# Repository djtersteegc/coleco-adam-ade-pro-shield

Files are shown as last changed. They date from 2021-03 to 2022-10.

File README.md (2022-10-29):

# coleco-adam-ade-pro-shield
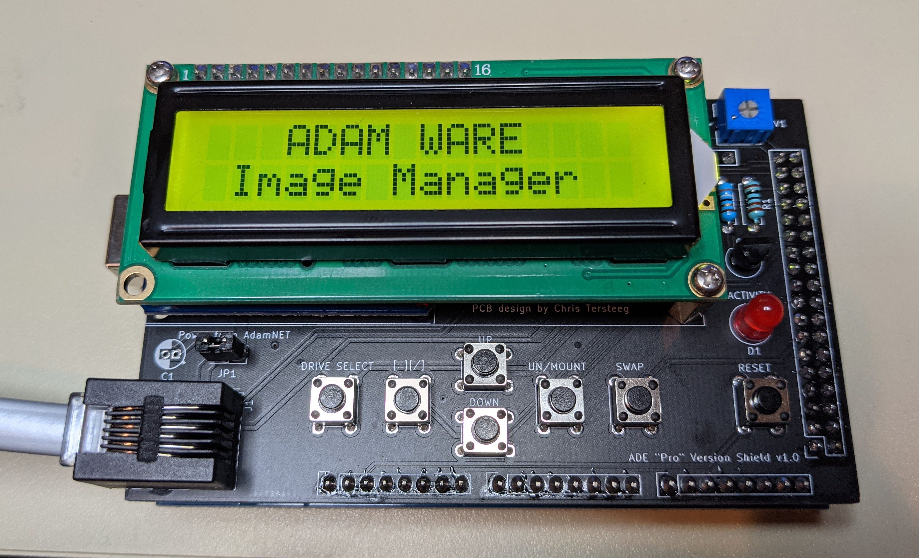
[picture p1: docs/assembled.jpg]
assembled


This custom Arduino Mega 2560 shield compatible with [AdamNet Drive Emulator](https://github.com/Kalidomra/AdamNet-Drive-Emulator) (ADE) software by Sean Myers. The design is built to be compatible with the "Pro" version of the software available precompiled and ready for flashing on his repo.  I was inspired by John Lundy's original ADE shield design, but wanted something with a slightly smaller footprint and different SD card module.  This was accomplished by putting the LCD on stand-offs and mounting the card (and some other components) underneath it.

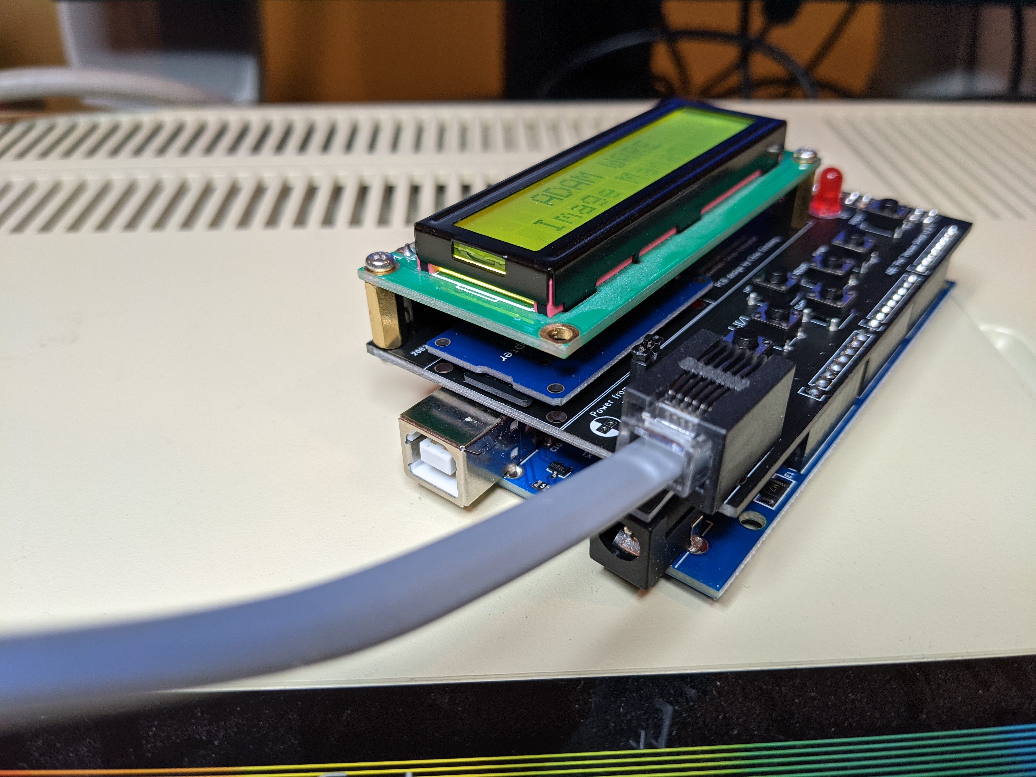
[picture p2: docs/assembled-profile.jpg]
assembled-profile


All components can be sourced from the usual low cost China based vendors for a total build cost of around $20.  Please see the assembly page for more details.

[Hardware Component Choices and Assembly](https://djtersteegc.github.io/coleco-adam-ade-pro-shield/assembly.html)

An interactive BOM and parts placement diagram is also available.

[Interactive Bill of Materials (BOM)](https://djtersteegc.github.io/coleco-adam-ade-pro-shield/ibom.html)

STL's and the [DesignSpark Mechanical](https://www.rs-online.com/designspark/mechanical-software) source file for a 3D printable enclosure are in the **enclosure** directory. There is a difference in power and USB connectors locations between the offical 2560 boards and the Chinese copies you can buy with the CH340 serial chips.  Pick the body file that matches the type you are using. The lid is snap fit, but you can also add a single M3x10mm screw if you wish to secure it further. Make sure to print seven copies of the button file.

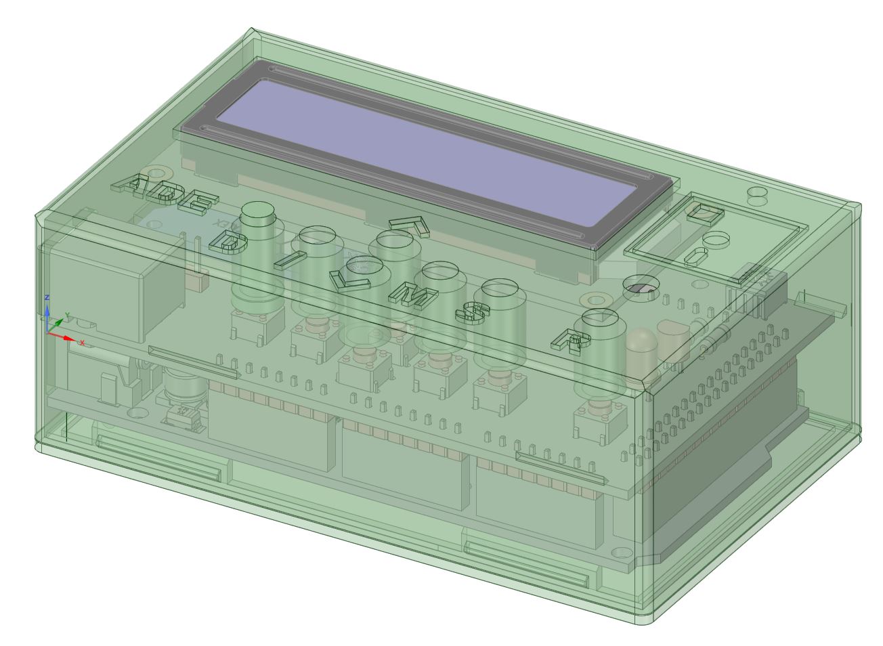
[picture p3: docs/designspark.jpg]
designspark


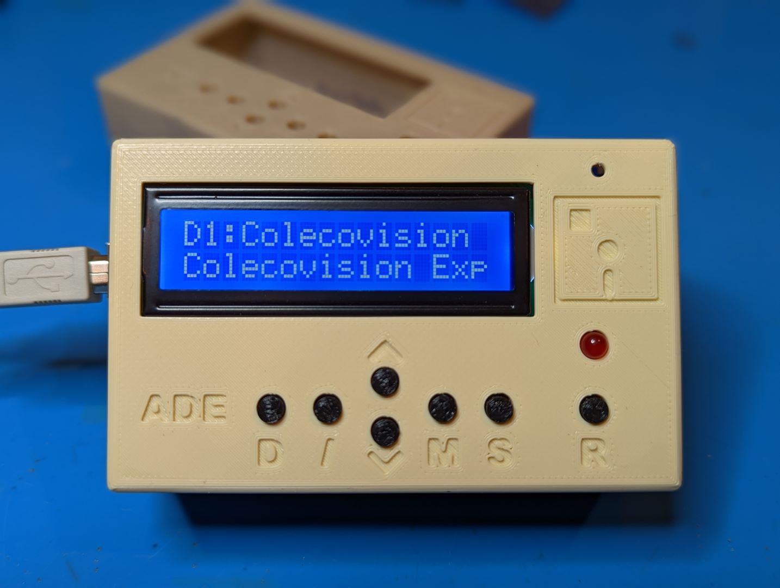
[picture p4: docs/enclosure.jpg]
enclosure


If you wish to power your board from the 5V ADAMnet line, simply install and close jumper JP1.  Be warned there is no protection on the board from back feeding voltage into the Adam if you also power the Arduino via USB or it's DC jack connector, so only close this jumper when not using another power source on the Arduino.

# Getting a Board

If I have extra PCB's, they will be listed on Tindie (soon...).

Otherwise you can download the Gerbers and use your favorite fab (JLCPCB, PCBWay, etc.) to make your own batch.  It's a standard two layer, 1oz copper board with dimensions of 99mm x 61mm so it squeaks under the 100mm x 100mm limit of the cheap Chinese fabs.

# Hardware Revisions

### Version 1.0

Tested and working.

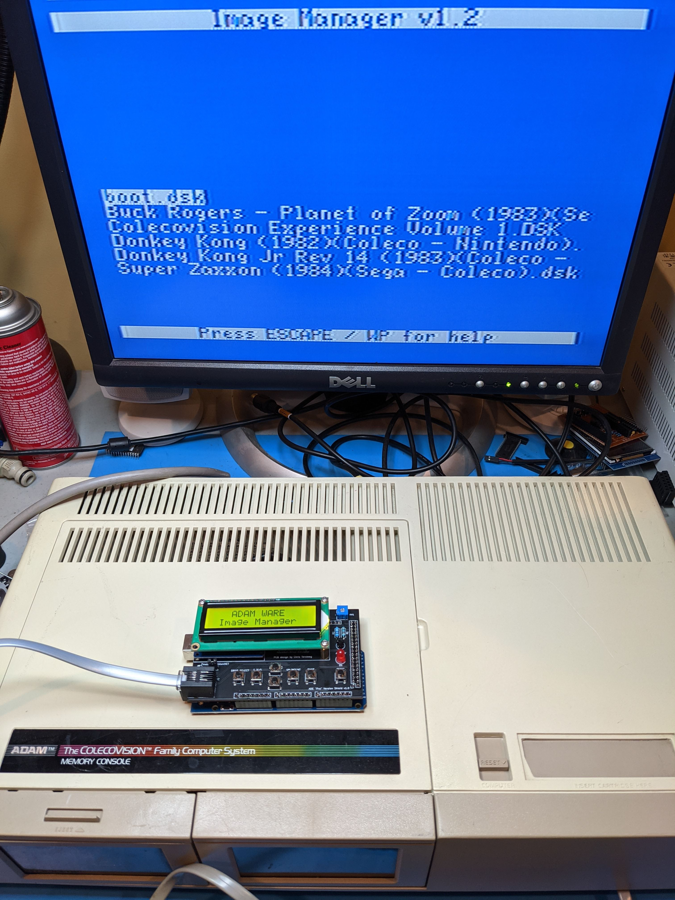
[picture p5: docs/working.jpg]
working


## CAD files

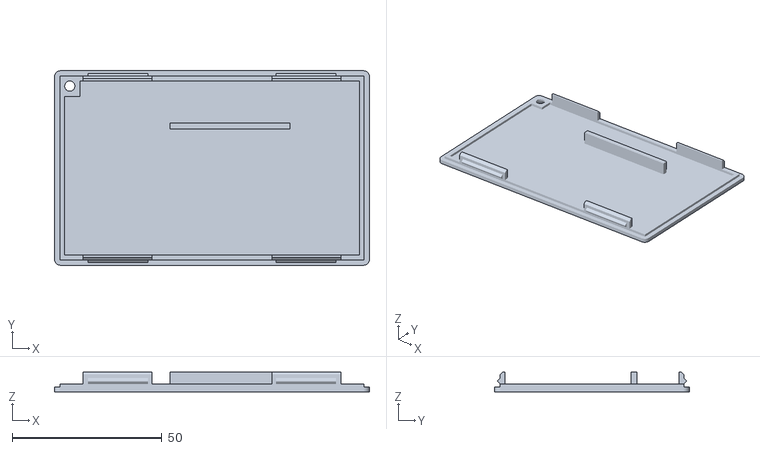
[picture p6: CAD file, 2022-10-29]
enclosure/ade lid.stl
105.2 x 65.0 x 6.60

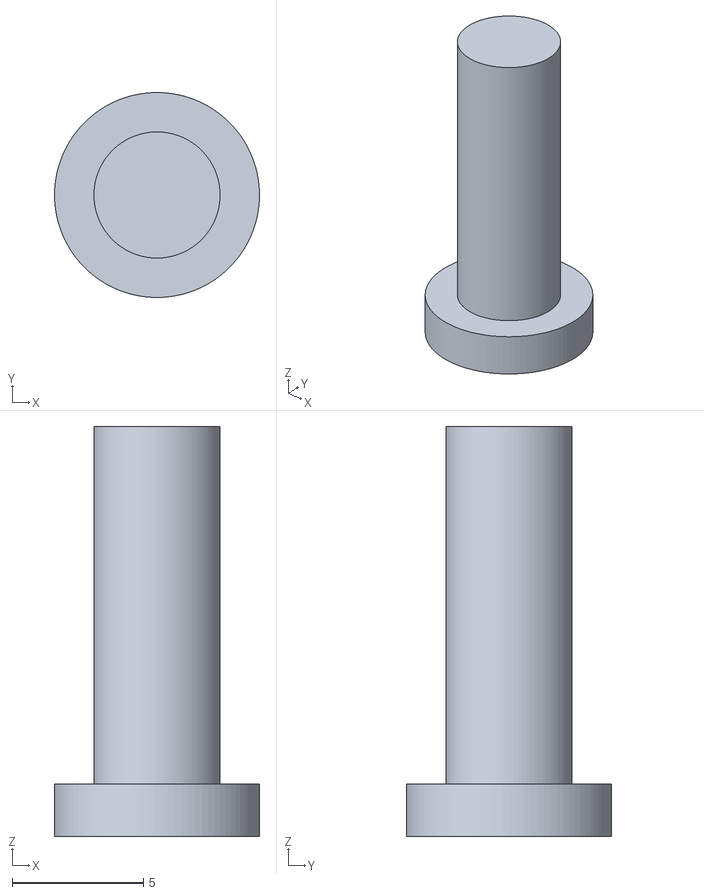
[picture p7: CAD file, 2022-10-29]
enclosure/ade button.stl
7.80 x 7.80 x 15.6

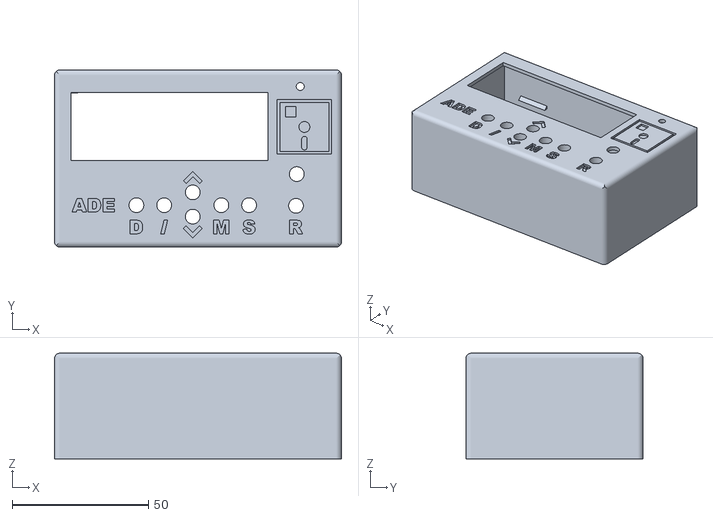
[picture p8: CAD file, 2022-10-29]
enclosure/ade body.stl
105.2 x 65.0 x 38.7

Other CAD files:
enclosure/ade body - ch340 clone.stl

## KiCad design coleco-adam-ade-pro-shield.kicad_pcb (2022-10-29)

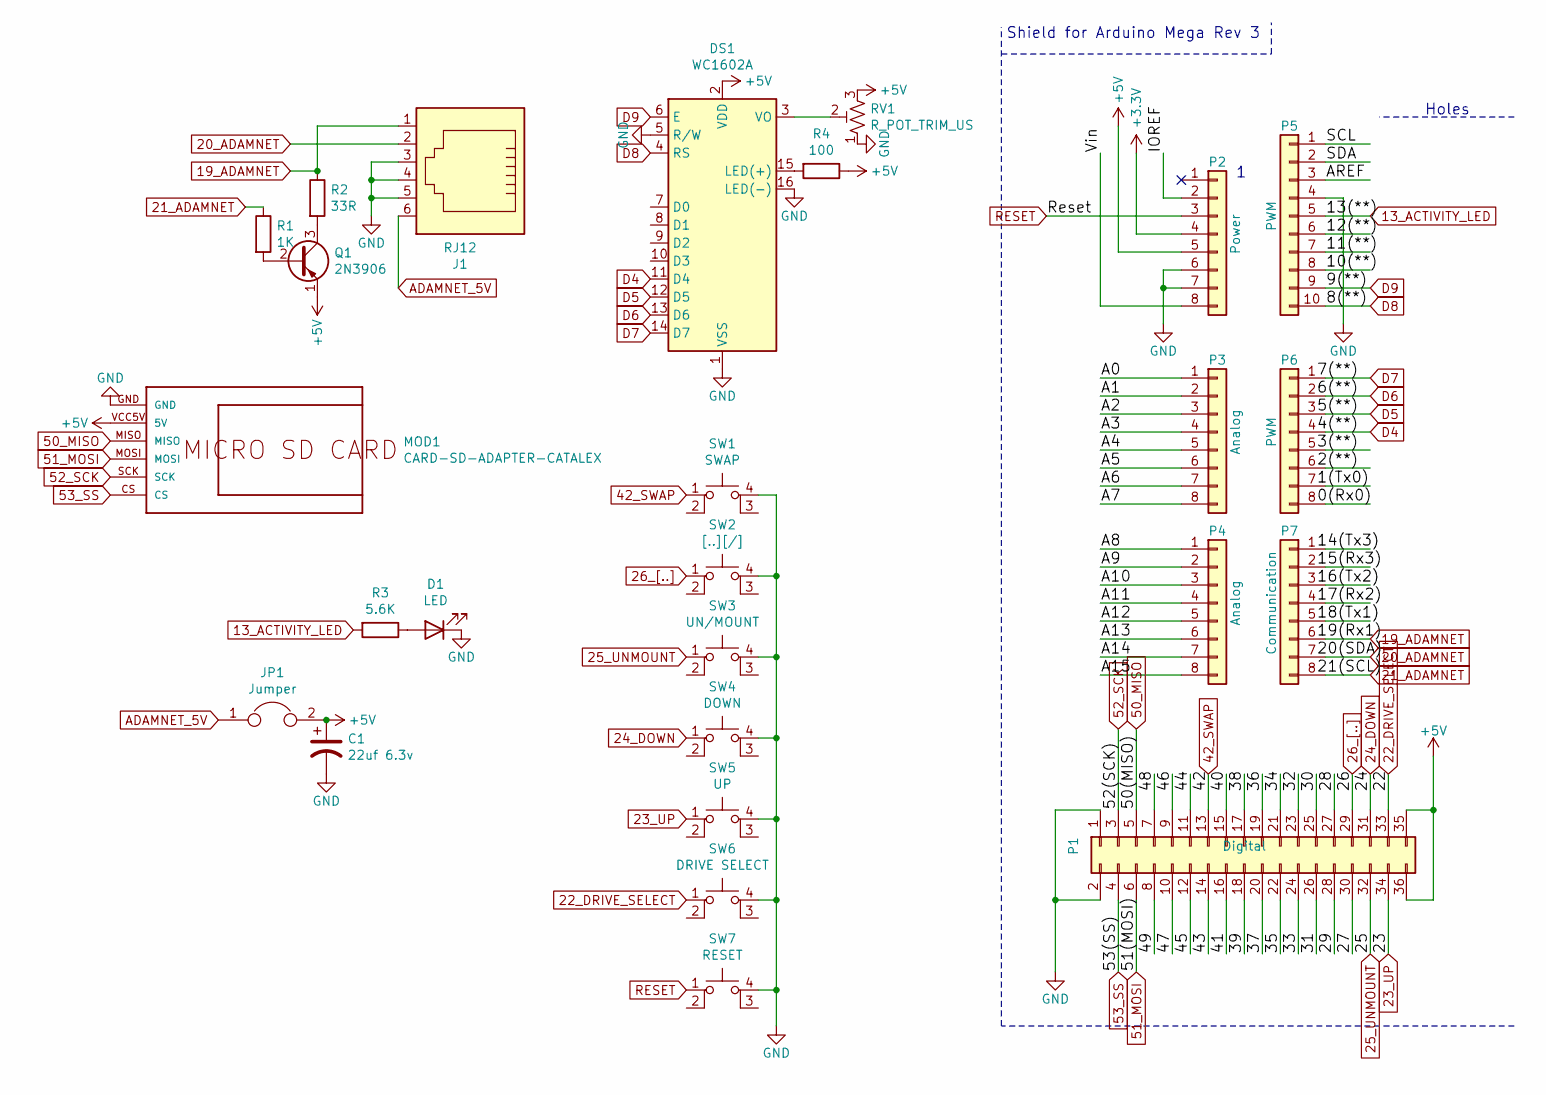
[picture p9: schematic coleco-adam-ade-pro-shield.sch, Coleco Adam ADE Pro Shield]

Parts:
C1: 22uf 6.3v; CP_Radial_D4.0mm_P1.50mm
D1: LED; LED_D5.0mm
DS1: WC1602A
J1: RJ12; RJ12_Amphenol_54601
JP1: Jumper; PinHeader_2x01_P2.54mm_Vertical
MOD1: CARD-SD-ADAPTER-CATALEX; Catalex-MicroSD-Card-Down
P1: Digital; Socket_Strip_Arduino_2x18
P2: Power; Socket_Strip_Arduino_1x08
P3, P4: Analog; Socket_Strip_Arduino_1x08
P5: PWM; Socket_Strip_Arduino_1x10
P6: PWM; Socket_Strip_Arduino_1x08
P7: Communication; Socket_Strip_Arduino_1x08
Q1: 2N3906; TO-92_Inline
R1: 1K; R_Axial_DIN0207_L6.3mm_D2.5mm_P7.62mm_Horizontal
R2: 33R; R_Axial_DIN0207_L6.3mm_D2.5mm_P7.62mm_Horizontal
R3: 5.6K; R_Axial_DIN0207_L6.3mm_D2.5mm_P7.62mm_Horizontal
R4: 100; R_Axial_DIN0207_L6.3mm_D2.5mm_P7.62mm_Horizontal
RV1: R_POT_TRIM_US; TRIM_3362P-1-103
SW1: SWAP; SW_TH_Tactile_Omron_B3F-10xx
SW2: [..][/]; SW_TH_Tactile_Omron_B3F-10xx
SW3: UN/MOUNT; SW_TH_Tactile_Omron_B3F-10xx
SW4: DOWN; SW_TH_Tactile_Omron_B3F-10xx
SW5: UP; SW_TH_Tactile_Omron_B3F-10xx
SW6: DRIVE SELECT; SW_TH_Tactile_Omron_B3F-10xx
SW7: RESET; SW_TH_Tactile_Omron_B3F-10xx

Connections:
13_ACTIVITY_LED: P5.5, R3.2
19_ADAMNET: J1.1, P7.6, R2.1
20_ADAMNET: J1.2, P7.7
21_ADAMNET: P7.8, R1.1
22_DRIVE_SELECT: P1.33, SW6.1
23_UP: P1.34, SW5.1
24_DOWN: P1.31, SW4.1
25_UNMOUNT: P1.32, SW3.1
26_[..]: P1.29, SW2.1
42_SWAP: P1.13, SW1.1
50_MISO: MOD1.MISO, P1.5
51_MOSI: MOD1.MOSI, P1.6
52_SCK: MOD1.SCK, P1.3
53_SS: MOD1.CS, P1.4
+3V3: P2.4
+5V: C1.1, DS1.2 (VDD), JP1.2, MOD1.VCC5V (5V), P1.35, P1.36, P2.5, Q1.1 (E), R4.1, RV1.3
/10(**): P5.8
/11(**): P5.7
/12(**): P5.6
/27: P1.30
/28: P1.27
/29: P1.28
/30: P1.25
/31: P1.26
/32: P1.23
/33: P1.24
/34: P1.21
/35: P1.22
/36: P1.19
/37: P1.20
/38: P1.17
/39: P1.18
/40: P1.15
/41: P1.16
/43: P1.14
/44: P1.11
/45: P1.12
/46: P1.9
/47: P1.10
/48: P1.7
/49: P1.8
/A0: P3.1
/A1: P3.2
/A2: P3.3
/A3: P3.4
/A4: P3.5
/A5: P3.6
/A6: P3.7
/A7: P3.8
/A8: P4.1
/A9: P4.2
/A10: P4.3
/A11: P4.4
/A12: P4.5
/A13: P4.6
/A14: P4.7
/A15: P4.8
/AREF: P5.3
/IOREF: P2.2
/SCL: P5.1
/SDA: P5.2
/Vin: P2.8
ADAMNET_5V: J1.6, JP1.1
D4: DS1.11 (D4), P6.4
D5: DS1.12 (D5), P6.3
D6: DS1.13 (D6), P6.2
D7: DS1.14 (D7), P6.1
D8: DS1.4 (RS), P5.10
D9: DS1.6 (E), P5.9
GND: C1.2, D1.1 (K), DS1.1 (VSS), DS1.5 (R/W), DS1.16 (LED(-)), J1.3, J1.4, J1.5, MOD1.GND, P1.1, P1.2, P2.6, P2.7, P5.4, RV1.1, SW1.4 (A), SW2.4 (A), SW3.4 (A), SW4.4 (A), SW5.4 (A), SW6.4 (A), SW7.4 (A)
unnamed: D1.2 (A), R3.1
unnamed: DS1.3 (VO), RV1.2
unnamed: DS1.15 (LED(+)), R4.2
unnamed: Q1.2 (B), R1.2
unnamed: Q1.3 (C), R2.2
RESET: P2.3, SW7.1

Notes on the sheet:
Shield for Arduino Mega Rev 3
Holes

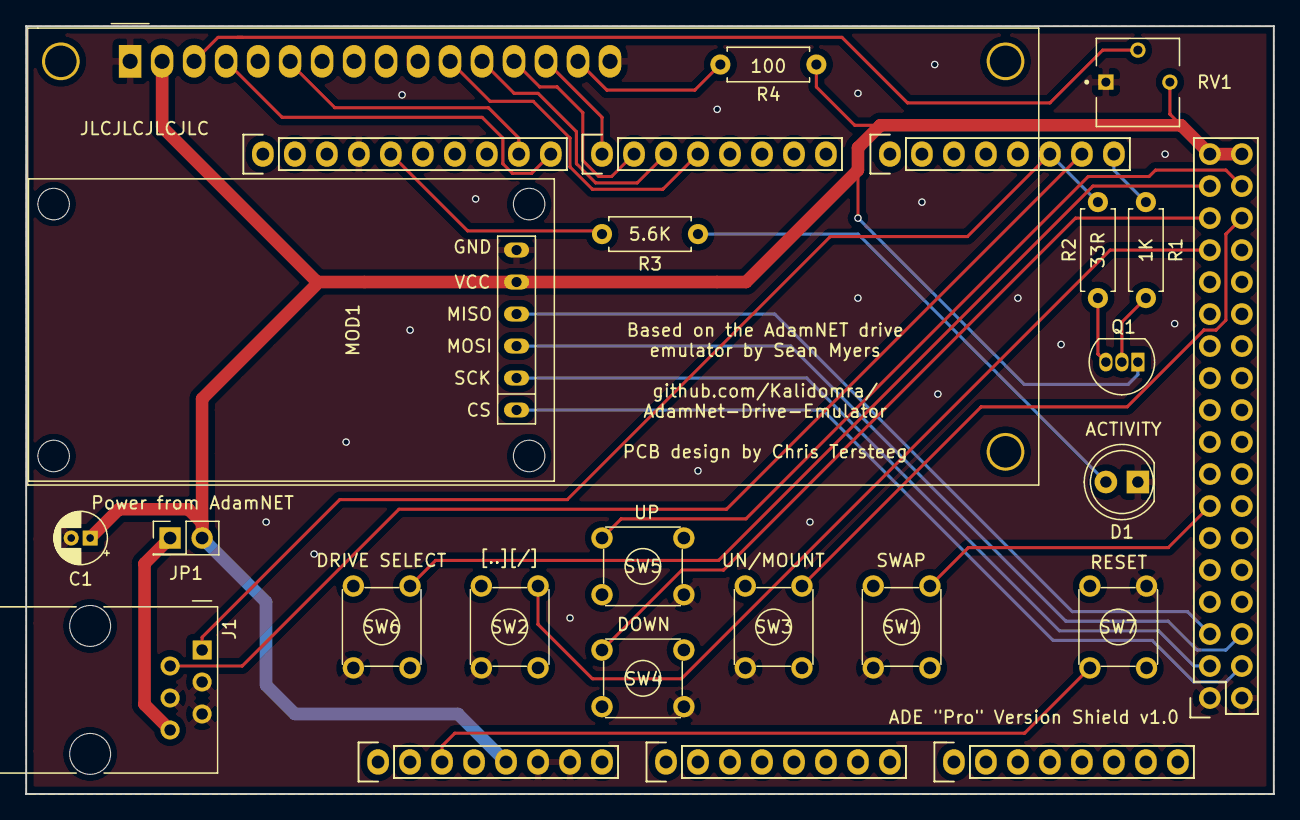
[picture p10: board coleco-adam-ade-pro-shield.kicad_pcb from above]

Board: 2 copper layers, 99.1 x 61.0 mm, 26 parts (0 on the bottom side), 29 nets.

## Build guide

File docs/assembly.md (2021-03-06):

# Hardware Component Choices and Assembly

[Interactive Bill of Materials (BOM)](ibom.html)

### LCD and Mounting

Any old HD44780 1602 LCD from Aliexpress/eBay for ~$2.  You do not need the I2C module, LCD is connected in 4bit parallel mode. For the stand-off mounts you need [11mm M2.5 spacers](https://www.aliexpress.com/item/1005001478740318.html) and screws (same as used mount a Raspberry Pi hat)

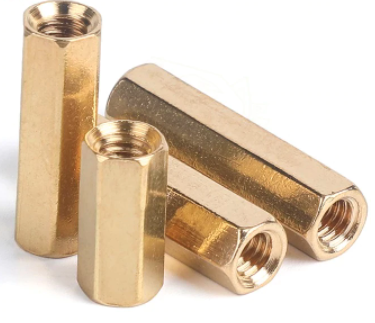
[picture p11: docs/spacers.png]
spacers
 

and a 16 pin (16p) female header.  I buy the  [40 pin packs](https://www.aliexpress.com/item/32724478308.html) and cut them down.

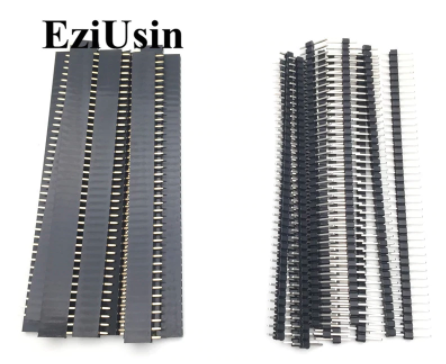
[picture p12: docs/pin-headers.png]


### Micro SD Card Connector

This is the common push-push [Micro SD module](https://www.aliexpress.com/item/1873549637.html) with level shifters.  Sometimes it may say "Catalex" (maybe the original designer?) on the back of the PCB.  You will need to remove the pre-soldered right angle header they all seem to come with so you can mount it upside down on the ADE shield board.

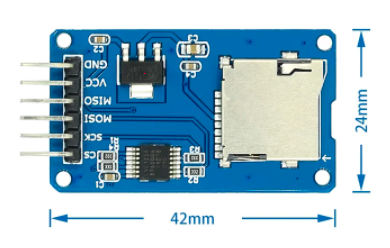
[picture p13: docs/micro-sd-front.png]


### RJ12 Connector

The "longer" type RJ12 connector from [Aliexpress](https://www.aliexpress.com/item/32865986654.html) work fine if you don't want to spring for the official [Amphenol](https://www.digikey.com/en/products/detail/amphenol-icc-fci/54601-906WPLF/4242891) version.  Remember, ADAMnet takes a RJ12 reverse cable, I get mine at [Monoprice](https://www.monoprice.com/product?p_id=939)

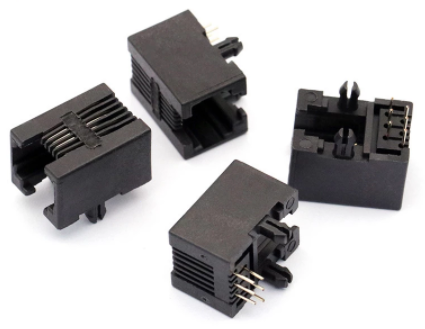
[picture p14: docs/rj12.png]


### Bulk Capacitors

C1 is a bulk storage capacitor for the 5V rail.  It is optional since the Arduino already has caps on-board, but if you have a marginal ADAMnet 5V line or experience other power issues, they could help stabilize the overall board.  Any value between 10uf to 47uf is fine.

### Resistors

Either 1/4W or 1/8W can be used in all locations.

R3 controls the activity LED brightness. The value listed is based on John Lundy's original shield design he published, but you may want to pick other values if using different LED's with different [Vf](https://electronics.stackexchange.com/questions/173468/easy-way-to-figure-out-a-leds-vf-in-order-to-pick-an-appropriate-resistor) values or prefer brighter or dimmer LEDs.  I generally shoot for around 1ma to 2ma of current on a standard 20ma LED depending on color. A good calculator is at:

[http://ledcalc.com/](http://ledcalc.com/)

R4 is for the LCD backlighting.  Some came without current limiting resistors on-board and needed an external.  [Inspect yours to see](https://electronics.stackexchange.com/questions/212197/is-it-necessary-to-use-resistor-when-connecting-backlight-of-16x2-lcd-display).  Even on ones that have a 100R resistor, I like to add another 100R here to cut down the brightness a bit.

### Arduino Pin Headers

The BOM shows stacking Arudino socket strip headers since that's what was in the Kicad Mega shield template, but since you are not going to stack anything on this shield, just use the standard [2.54mm male pin headers](https://www.aliexpress.com/item/32724478308.html) you see everywhere.  You can even use two 1x18 strips instead of a 2x18 for the end connector on the Mega.

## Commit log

2021-02-28 Initial version sent to JCL
    [coleco-adam-ade-pro-shield-B_Cu.gbr, coleco-adam-ade-pro-shield-B_Mask.gbr, coleco-adam-ade-pro-shield-B_SilkS.gbr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]
2021-03-06 Add some docs
    [coleco-adam-ade-pro-shield.kicad_pcb, coleco-adam-ade-pro-shield.sch]
2022-10-29 Fixup 3D models
    [coleco-adam-ade-pro-shield.kicad_pcb]
2022-10-29 Add enclosure
    [ade body - ch340 clone.stl, ade body.stl, ade button.stl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]
